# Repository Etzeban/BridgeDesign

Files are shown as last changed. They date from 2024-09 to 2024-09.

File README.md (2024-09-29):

<h1>Design a brigde made of Acrylic</h1>

<h2>Description</h2>
Project Manager in a team of 3 students to design and analyze the loading conditions of a simple bridge and redesign the bridge such that it can bear the loading requirements. Responsible for project management, keep the project aligns with requirements, assembling and testing the bridge.
<br />
The loading requirements stipulated below:
<br />
1. The bridge shall span a chasm that measures 500 mm from one edge to the other.
<br />
2. The bridge shall be made entirely of Acrylic and held together by glue. No mechanical fastener shall be allowed.
<br />
3. The bridge shall have guard rails and allow for 1 way traffic. The traffic will be for 2 PAScars. The guard rails should be implemented for the 500 mm unsupported length only.
<br />
4. The combined load of these PAScars shall be 8 kg maximum. The bridge's allowable stress is recommended to have a tensile safety factor of 1.5 when under this load.
<br />
5. The bridge shall not be damaged or disintegrated in any way as the PAScars travel through it (multiple times).
<br />
6. The maximum deflection point on the bridge shall not prevent the PAScar from crossing it or be more than 5 mm as the PAScars travel through it, whichever is lesser.
<br />
7. The bridge shall connect seamlessly into the 1.2 meters PASCO dynamics track at both ends.
<br />
8. The bridge shall only be fix-supported at 1 end. The fix-support shall be done by 2 hand-clamps at the first 100 mm length of the bridge (without any guard rail). No human contact shall be permitted to provide support for the bridge.
<br />
9. The bridge shall bear permanent markings to identify which team it belongs to. Failure to do so could lead to your bridge being lost and you will receive no credit for the demonstration.
<br />

<h2>Project's snapshots</h2>

<p align="center">
Final assembled bridge design in SolidWorks: <br/>
Disk Sanitization Steps
<br />
<br />
The bridge exploded view in SolidWorks: <br/>
Disk Sanitization Steps
<br />
<br />
Technical drawing of the deck: <br/>
Disk Sanitization Steps
<br />
<br />
Technical drawing of the I beam supports: <br/>
Disk Sanitization Steps
<br />
<br />
Technical drawing of the guards:  <br/>
Disk Sanitization Steps
<br />
<br />
Sheer diagram when the distributed load at the end of the bridge:  <br/>
Disk Sanitization Steps
<br />
<br />
Moment diagram when the distributed load at the end of the bridge:  <br/>
Disk Sanitization Steps
<br />
<br />
Sheer diagram when the distributed load at the middle of the bridge:  <br/>
Disk Sanitization Steps
<br />
<br />
Moment diagram when the distributed load at the middle of the bridge:  <br/>
Disk Sanitization Steps
<br />
<br />

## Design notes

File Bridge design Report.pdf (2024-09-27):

# MIET2499 STRESS ANALYSIS

# MINI-PROJECT # 2

# BRIDGE DESIGN

Date: May 17, 2022

Course/Section: MIET2499 Stress Analysis

Lecturer: Mr.Trung Nguyen

Team Members: Do Le Tri Dung - s3852872

Nguyen Quoc Hung - s3752578

C

MIET 2499 Stress Analysis

# Table of Contents

Introduction & Theory | 2
Design Proposal and Analysis | 3
Design Overview | 4
Design Load Cases | 7
A. Scenario 1: distributed load at the end | 7
Maximum Stress Analysis | 7
Deflection Analysis | 8
B. Scenario 1: distributed load at the middle | 9
Maximum Stress Analysis | 9
Deflection Analysis | 10
Conclusion | 11
References | 11

# I. Introduction & Theory

a.

In this project, our group is required to design a bridge that can sustain the weight of 2 Pasco cars without deflecting more than 5mm. The fundamental support of the bridge was simple, one of its ends is fixed to the Pasco track and the second end has no reaction force to be strengthened. The purpose of this project is for students to utilize the principles of Stress Analysis to increase the durability of the second end of the bridge and fulfill the requirements. In addition, we need to determine all the loads acting on the bridge to find the support force needed.

b. For this project to be well calculated, we will need at least these 3 theoretical principles to be considered:

The first principle we need to calculate is the bending stress of the beam where the load acts on a particular point and produces stress inside the beam. This result is used to find the stress value that the beam experienced. Therefore, it serves the design process to make the bridge more sustainable.

- The bending stress happens on the bridge:

The second principle is the longitudinal shear stress where the shear force acting on the beam causes the surface areas to stress. This result is also required to analyze the stress in the parallel direction of the beam surface.

- Longitudinal shear stress:

The final fundamental principle is the deflection of the beam where different types of loads acting on the beam surface cause the bending moment that deflects the beam at an angle from the original coordinates.
- Beam deflection:
Each of the principles above has the same value of I that is relevant to all the equations, Therefore, after finding all of the maximum stress and deflection, we can determine a suitable I value to sustain the loads and design qualified support to minimize the deflection of the bridge.
There are some different equations that support the calculation:
- Shear diagram’s equation:
- Moment diagram’s equation:

- Safety factor:
- Elastic curve equation:

c.
During the project, there might have been some errors due to the theoretical calculations and actual environment differences. Additionally, errors from the design might also come from the design sketching phase or installation of each part of the bridge. For example, we might glue each part in error dimension or the completed product might be unsatisfactory due to the manual assembly. Furthermore, errors can occur if we use the wrong equations or round up the result values, in some cases, the material condition affected by temperature or time can also be a factor to cause an error.
d. There are some requirements from the project that can’t change:
- The total mass of the load ( 2 Pasco carts) is 8 kg, which means:
- The maximum deflection of the bridge must be smaller than 5 mm.
- The maximum allowable material is 3000 cm

2
- The thickness of each Acrylic part is 3 mm.
- The bridge span is 0.5 m: .
- The safety factor is 1.5: .

On the other hand, the moment of inertia, maximum bending and shear stress, and maximum deflection of the beam are the parameters that can be moderated by calculation and mostly depend on the design qualification.

e.

# II. Design Proposal and Analysis

## Design Overview

After applying relevant theories and optimal solutions for the problem, the shape of the bridge is considered to be an I beam which is appropriate to utilise formulas and design.

Specifically, the design will include 1 upper deck which is provided at the beginning of the project, 1 lower deck with the same dimension as the upper one to reinforce the bridge, 5 supports to increase the load endurance, and 2 guard rails to prevent the vehicles from deviation.

In this design, the upper deck, lower deck, and 5 supports will be designed with the same length to create a strong and tough block. Besides, the I shape is an optimal choice to have high moments of inertia that will diminish the bending stress and deflection, which is the purpose of the project [https://northern-weldarc.com/why-are-i-beams-used-in-steel-construction/].

The pictures below illustrate the bridge in the normal and exploded view and its fully dimensioned orthographic drawing:

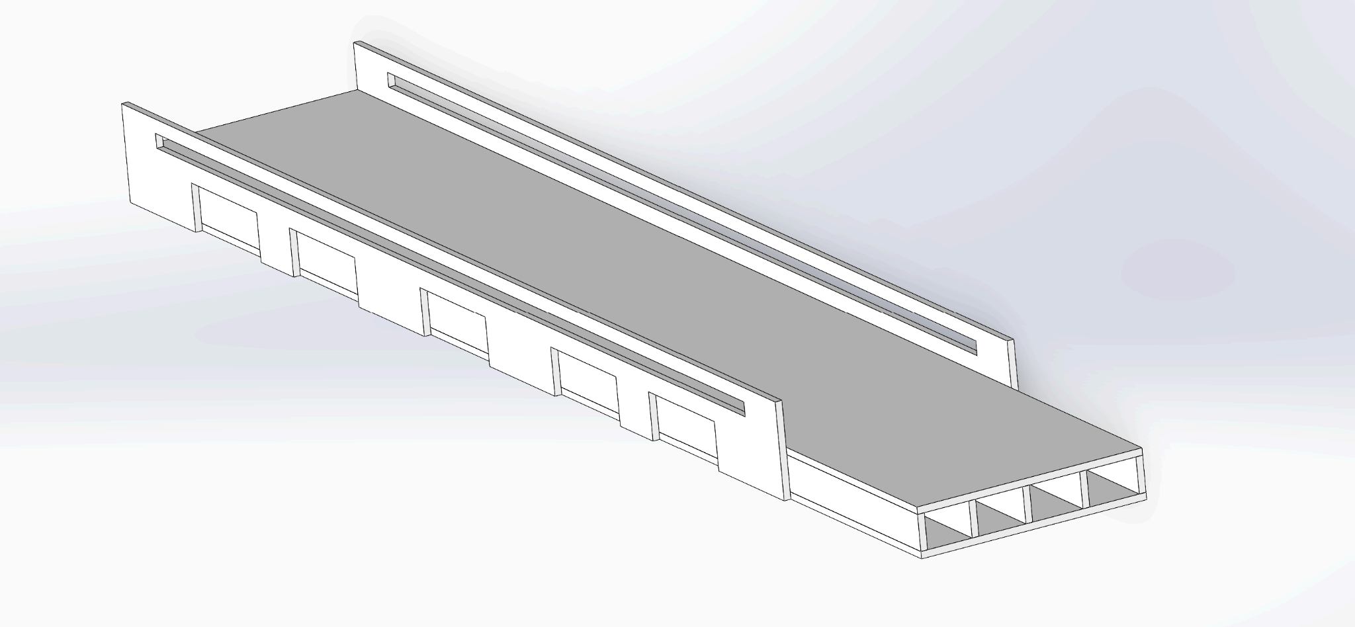
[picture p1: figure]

Figure: The complete bridge

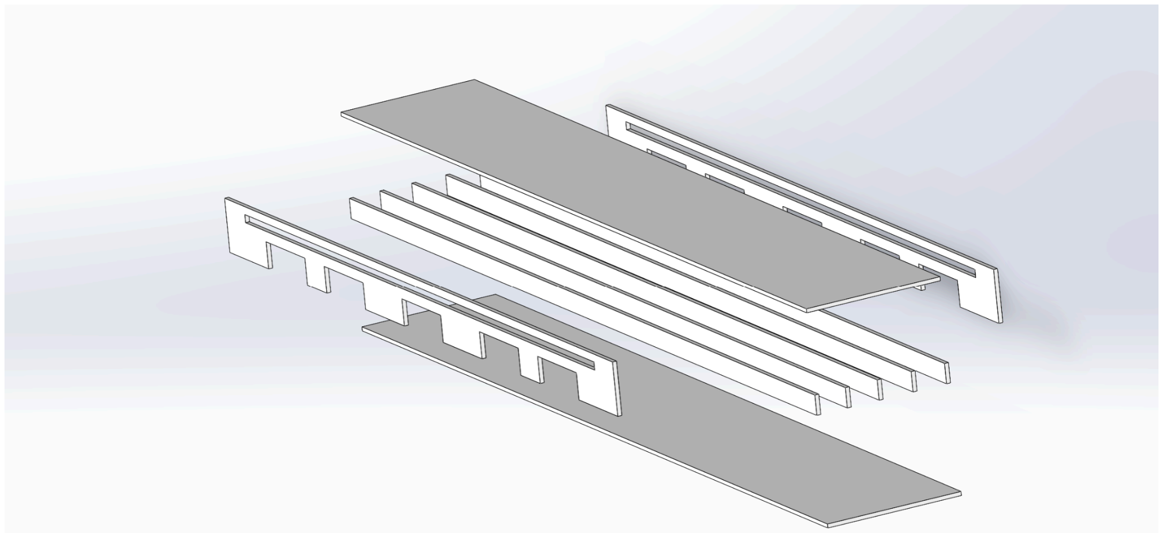
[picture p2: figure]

Figure: The bridge in the exploded view

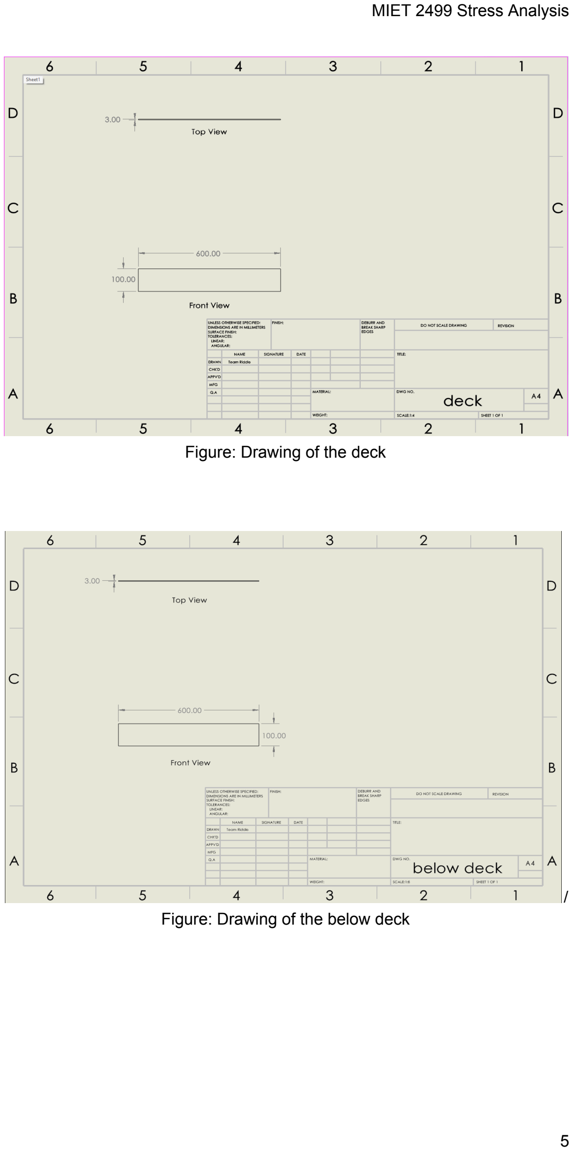
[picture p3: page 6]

Figure: Drawing of the deck

/
Figure: Drawing of the below deck

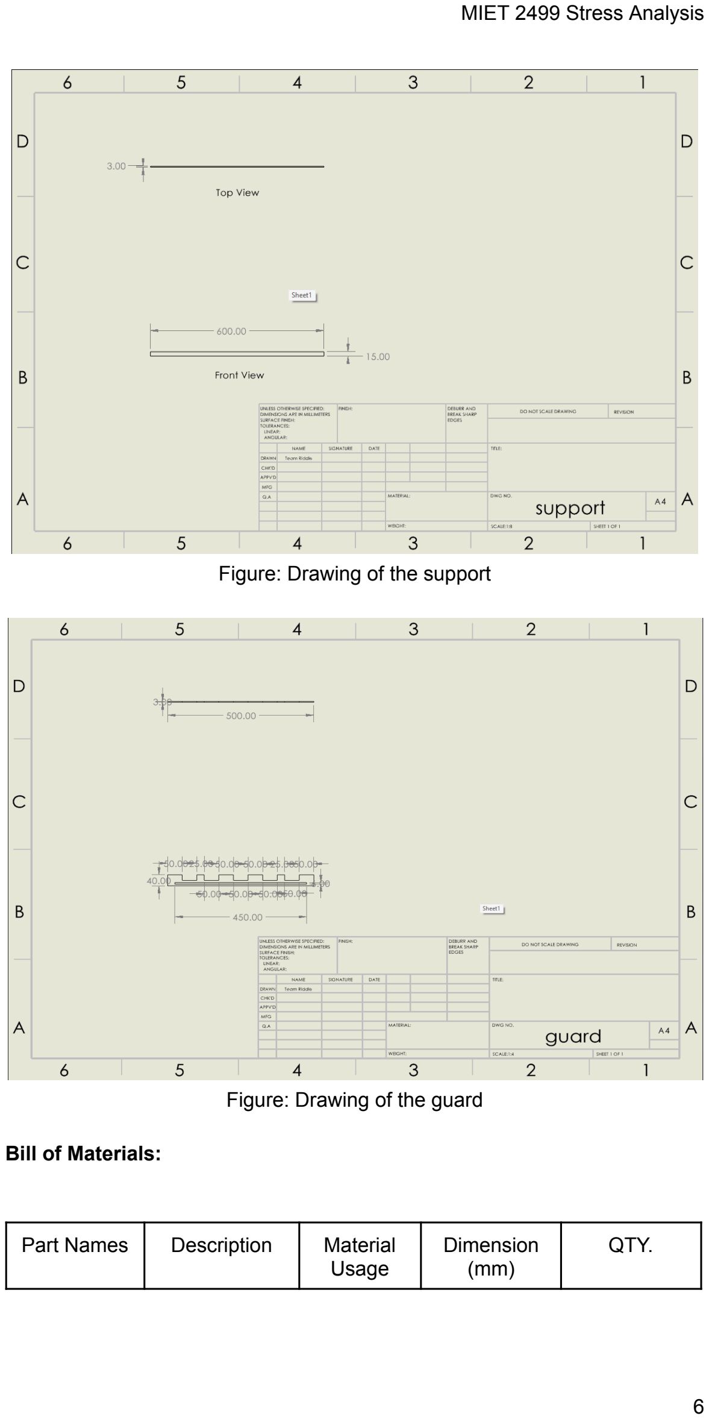
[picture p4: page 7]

Figure: Drawing of the support

Figure: Drawing of the guard

Bill of Materials:

Part Names | Description | Material Usage

Dimension
(mm)

QTY.

Deck | The upper surface of the bridge which is provided at the beginning of the project | 2 1242 cm PMMA | Length: 600 Width: 100 Height: 3 | 1
Below deck | Another deck under the provided bridge deck to increase the endurance | 2 1242 cm PMMA | Length: 600 Width: 100 Height: 3 | 1
Support | Increase the endurance | 2 216.9 cm PMMA | Length: 600 Width: 15 Height: 3 | 5
Guard Rail | To prevent the car from deviation | 2 311.76 cm PMMA | Length: 500 Width: 40 Height: 3 | 2

## Design Load Cases

A. Scenario 1: distributed load at the end

## a. Maximum Stress Analysis

Maximum allowable tensile stress = 48/1.5 = 32 MPa
Maximum allowable compressive stress = 117.2 / 1.5 = 78.1 MPa
The second moment of inertia:
I = 2[1/12(100)(3)^3 +(100)(3)(12)^2] + 5[1/12(3)(15)^3] = 91068.75 mm4

The first moment of inertia:

Feq = w.L = 8*9.81 * 0.32 = 25.11 N

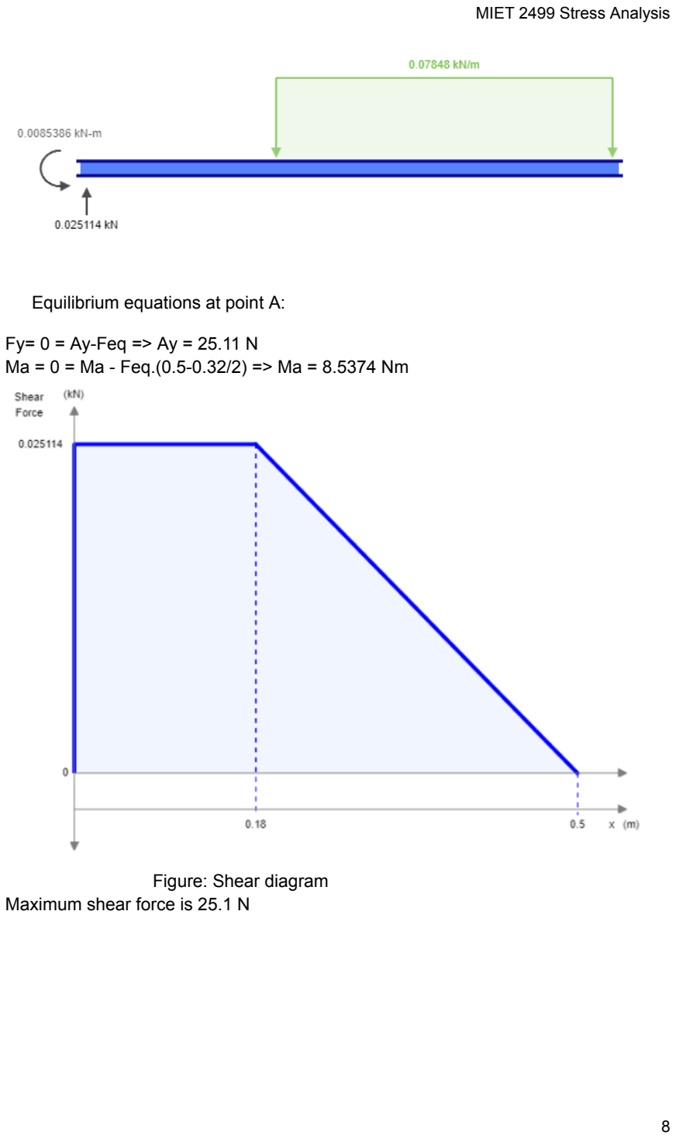
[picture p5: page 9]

Equilibrium equations at point A:

Fy= 0 = Ay-Feq => Ay = 25.11 N
Ma = 0 = Ma - Feq.(0.5-0.32/2) => Ma = 8.5374 Nm

Figure: Shear diagram
Maximum shear force is 25.1 N

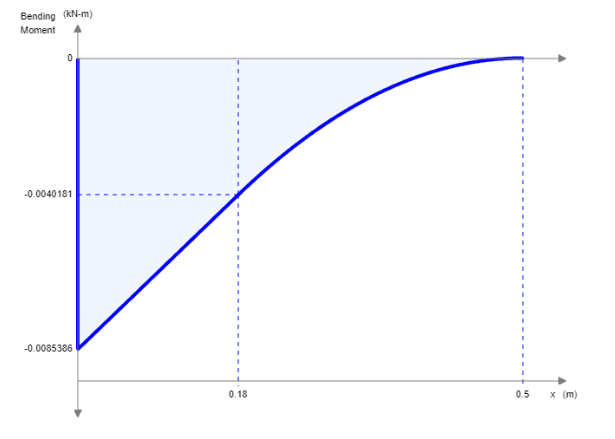
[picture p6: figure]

Figure: Moment diagram

Maximum moment is -8.5 Nm
Maximum tensile bending stress = M.y / I = [8.5 . (0.021/2)]/ 9.1069.10^-8 = 980026 Pa = 1 MPa
The maximum tensile bending stress in this case is smaller than the safety factor for maximum tensile bending stress (1 MPa < 32MPa)

Maximum compressive bending stress = 1 MPa
The maximum compressive bending stress in this case is smaller than the safety factor for maximum compressive bending stress (1 MPa < 78.1MPa)

Maximum longitudinal shear stress =VQ/It

The location of maximum shear stress and bending moment in this case is at the location 0mm and the fixed support is bearing that stress

## b. Deflection Analysis

The maximum radius of curvature of the bridge

= 3000.10^6 . 9.1069.10^-8 / 8.5 = 32.142 m

Slope at end = P.a^2/2EI = 25.1x 340^2/ 2x3000x91068 = 0.0053 rad = 0.03 degree

Maximum deflection = P.a^2/6.EI . (3L -a) = 25.1(340)^2/6.3000.91068 . (3.500-340) = 2.05mm [1]

Figure: Illustration for the Elastic Curve of the bridge

The maximum deflection in this case is smaller than the requirement for maximum deflection so the cars can pass (2.05 mm < 5mm). The maximum deflection will occur at location 500mm or the end of the bridge.

## B. Scenario 1: distributed load at the middle

## a. Maximum Stress Analysis

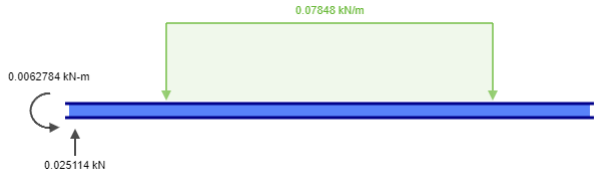
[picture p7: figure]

Equilibrium equations at point A:

Fy= 0 = Ay-Feq => Ay = 25.11 N
Ma = 0 = Ma - Feq.0.25 => Ma = 6.278 Nm

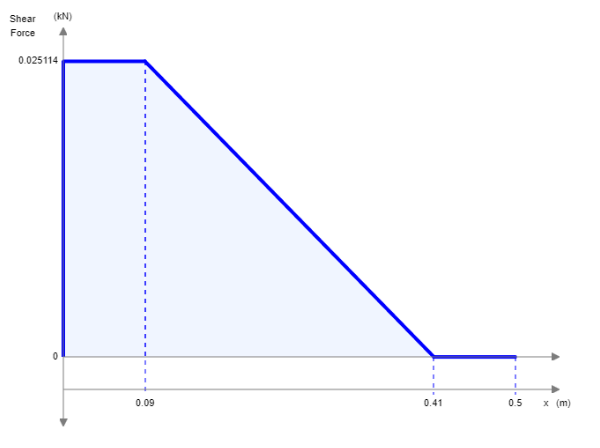
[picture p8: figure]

Figure: Shear diagram
Maximum shear force is 25.1 N

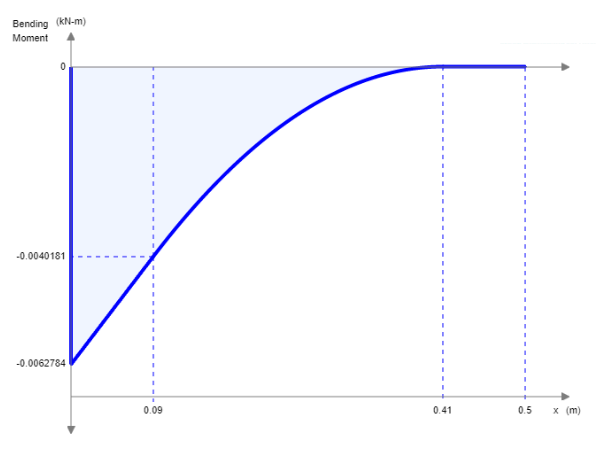
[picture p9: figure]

Figure: Moment diagram

Maximum moment is -6.278 Nm
Maximum tensile bending stress = M.y / I = [6.278 . (0.021/2)]/ 9.1069.10^-8 = 723835MPa = 0.72 MPa
The maximum tensile bending stress in this case is smaller than the safety factor for maximum tensile bending stress (0.72 MPa < 32MPa)

Maximum compressive bending stress = 0.72 MPa
The maximum compressive bending stress in this case is smaller than the safety factor for maximum compressive bending stress (0.72 MPa < 78.1MPa)

Maximum longitudinal shear stress =VQ/It

The location of maximum shear stress and bending moment in this case is also at the location 0mm and the fixed support is bearing that stress

## b. Deflection Analysis

The maximum radius of curvature of the bridge

= 3000.10^6 . 9.1069.10^-8 / 6.278 = 43.52 m

Slope at end = P.a^2/2EI =25.1x 250^2/ 2x3000x91068 = 0.0029 rad = 0.17 degree

Maximum deflection = P.a^2/6.EI . (3L -a) = 25.1(250)^2/6.3000.91068 . (3.500-250) = 1.2 mm

Figure: Illustration for the Elastic Curve of the bridge

The maximum deflection in this case is smaller than the requirement for maximum deflection so the cars can pass (1.2 mm < 5mm). The maximum deflection will occur at location 500mm or the end of the bridge.

# III. Conclusion

B.
max traffic can be on the bridge at the same time 500/160 = 3.125 cars Combined load of 3.125 cars = 4 x 3.125 = 12.5 kg

Feq = w.L = 12.5*9.81 * 0.5 = 61.3 N

Equilibrium equations at point A:

Fy= 0 = Ay-Feq => Ay = 61.3 N
Ma = 0 = Ma - Feq.0.25 => Ma = 15.325 Nm

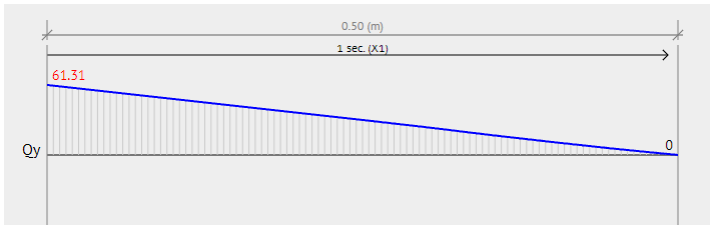
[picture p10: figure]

Figure: Shear diagram
Maximum shear force is 61.3 N

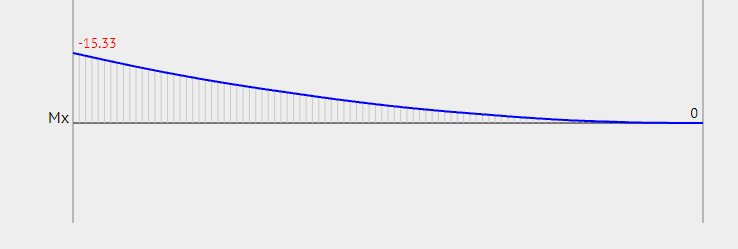
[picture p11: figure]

Figure: Moment diagram
Maximum moment is -15.325 Nm
Maximum tensile bending stress = M.y / I = [15.325 . (0.021/2)]/ 9.1069.10^-8 = 1766929 Pa = 1.77 MPa

Maximum compressive bending stress = 1.77 MPa

Maximum longitudinal shear stress =VQ/It

The maximum tensile and compressive bending stress is under the Acrylic safety factor for tensile(1.77MPa < 32 MPa) and compressive( 1.77MPa < 78.1 MPa) bending stress. The bridge will hold when all the cars travel at once on the bridge

Slope at end = w.L^3/6EI =122.625x 500^3/ 6x3000000x91068 = 0.009 rad = 0.5 degree

Maximum deflection = w.L^4/8EI = 122.625x(500)^4/8.3000000.91068 = 3.57 mm [1]

The maximum deflection compare to the allowable 5mm deflection for the cars to pass is smaller (3.57mm < 5mm). So the traffic can pass through the bridge

# IV. References

[1]https://mathalino.com/reviewer/strength-materials-mechanics-materials/met hod-superposition-beam-deflection (https://mathalino.com/reviewer/strength-materials-mechanics-materials/method-superposition-beam-deflection)

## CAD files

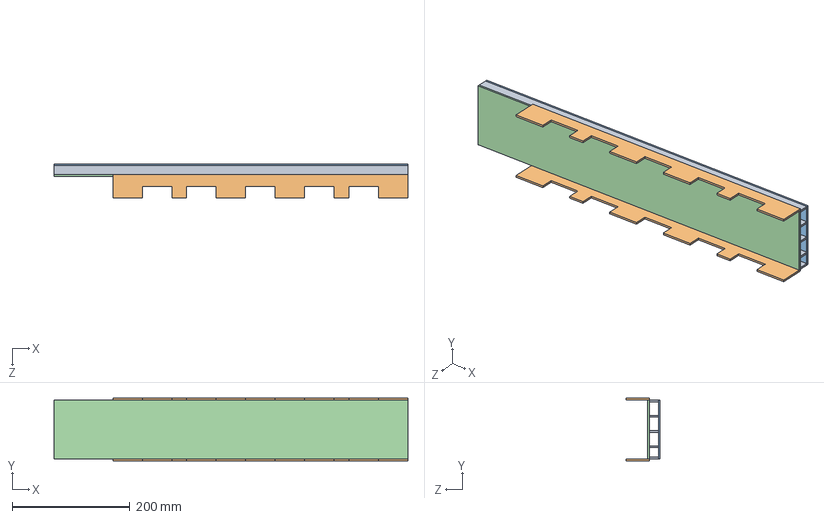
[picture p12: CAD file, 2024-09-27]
assembly.sldasm
600.0 x 106.0 x 58.0 mm
deck
below-deck
guard x 2
support x 5

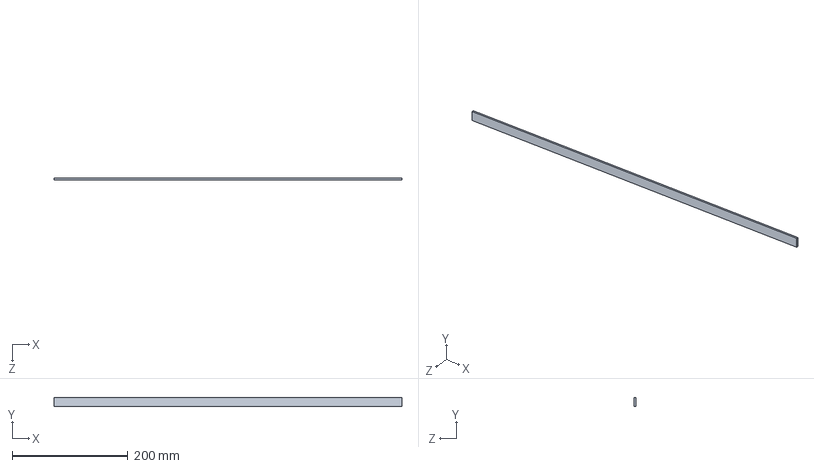
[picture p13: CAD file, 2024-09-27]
support.sldprt
600.0 x 15.0 x 3.00 mm

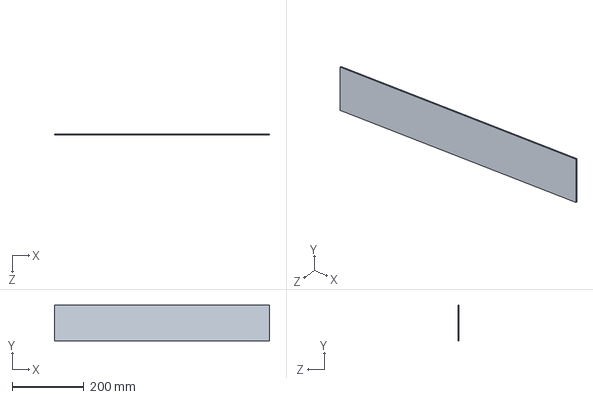
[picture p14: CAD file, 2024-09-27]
below-deck.sldprt
600.0 x 100.0 x 3.00 mm

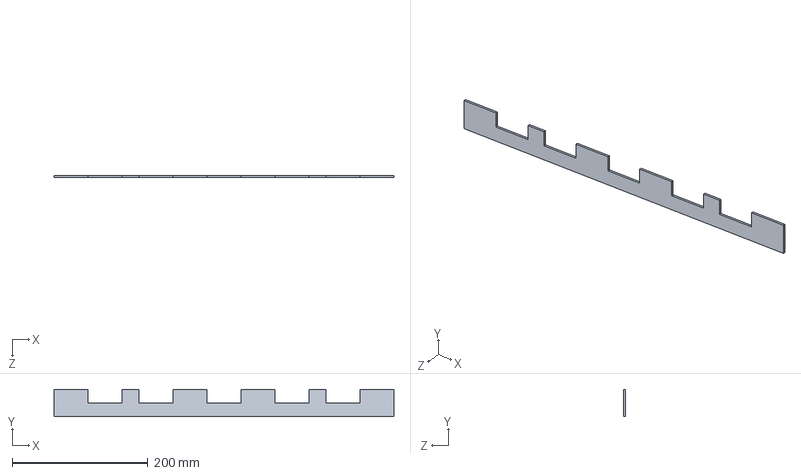
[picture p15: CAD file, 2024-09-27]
guard.sldprt
500.0 x 40.0 x 3.00 mm

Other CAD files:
deck.sldprt
